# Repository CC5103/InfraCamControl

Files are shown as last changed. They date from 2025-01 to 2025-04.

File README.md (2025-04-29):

# InfraCamControl

**Other Language Versions: [English](README.md) | [中文](README_zh.md) | [日本語](README_jp.md)**

---

## Table of Contents

- [InfraCamControl](#infracamcontrol)
  - [Table of Contents](#table-of-contents)
  - [Overview](#overview)
  - [Features](#features)
  - [Hardware Requirements](#hardware-requirements)
    - [Hardware Diagram](#hardware-diagram)
    - [PiCamera2 Module Filter Adjustment](#picamera2-module-filter-adjustment)
  - [Software Requirements](#software-requirements)
  - [Installation Guide](#installation-guide)
  - [Usage Instructions](#usage-instructions)
  - [System Architecture](#system-architecture)
  - [Face Detection Solutions](#face-detection-solutions)
    - [1. OpenCV Haar Cascade](#1-opencv-haar-cascade)
    - [2. YOLOv8](#2-yolov8)
    - [3. Ultra-Light-Fast](#3-ultra-light-fast)
    - [4. MediaPipe Face Mesh](#4-mediapipe-face-mesh)
  - [Hand Gesture Recognition](#hand-gesture-recognition)
  - [Hardware Connections](#hardware-connections)
  - [Contributing](#contributing)
  - [License](#license)
  - [Troubleshooting](#troubleshooting)
  - [Acknowledgments](#acknowledgments)

---

## Overview

InfraCamControl is a multifunctional smart camera control system based on Raspberry Pi, integrating infrared remote control, computer vision, and gesture recognition technologies. It receives instructions via Slack, supports infrared device control, face and gesture recognition, and automatically adjusts infrared lighting based on ambient light conditions. The system also supports voice interaction with Apple devices, enabling more intelligent device interaction.

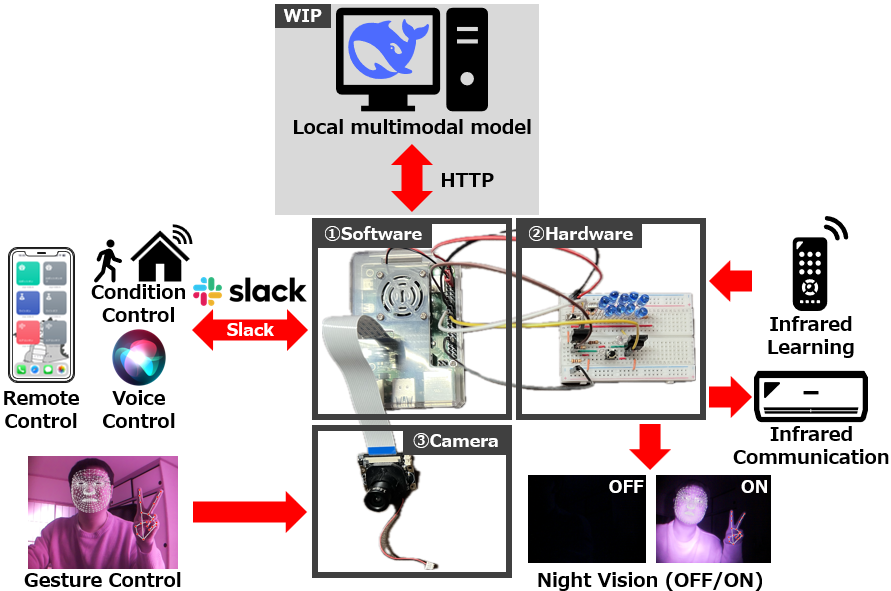
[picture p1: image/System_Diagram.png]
System Diagram


---

## Features

- **Remote Control**: Efficient remote management via Slack.
- **Infrared Learning and Sending**: Supports learning and sending infrared signals.
- **Computer Vision**:
  - Supports multiple face detection methods.
  - Real-time hand gesture recognition.
- **Ambient Light Management**: Automatically adjusts infrared lighting based on light conditions.
- **Multitasking**: Supports multithreading for improved efficiency.
- **Protocol Compatibility**: Supports NEC and Mitsubishi infrared protocols.
- **Apple Device Integration**: Enables smarter control via voice recognition.

---

## Hardware Requirements

- **Raspberry Pi** (Model 4B)
- **PiCamera2** (OV5647 IR-CUT)
- **Infrared LED Emitters** (OSI5LA5A33A-B 940nm) ×9
- **Red LED Indicator Light** (2.3V, 25mA)
- **Diode** (1N5819)
- **Infrared Receiver Module** (OSRB38C9AA)
- **N-channel MOSFETs** (2SK2232) ×2
- **Slide Switch**
- **Button**
- **Resistors**:
  - 2.2Ω (±5%) ×3
  - 10Ω (±5%) ×1
  - 100Ω (±5%) ×1
  - 10kΩ (±5%) ×2

### Hardware Diagram

<div style="display: flex; justify-content: space-between;">
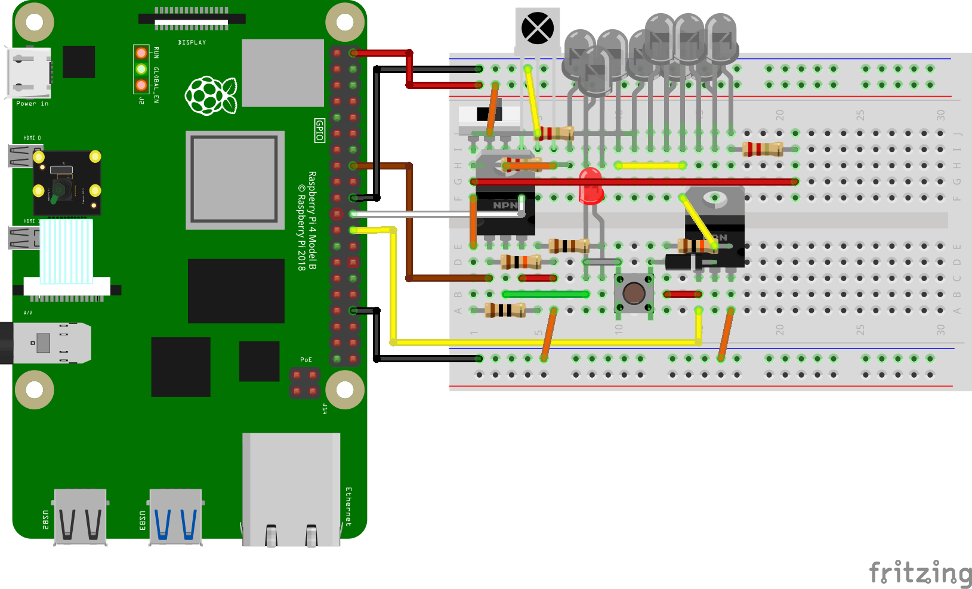
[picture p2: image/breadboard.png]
Breadboard Diagram
  
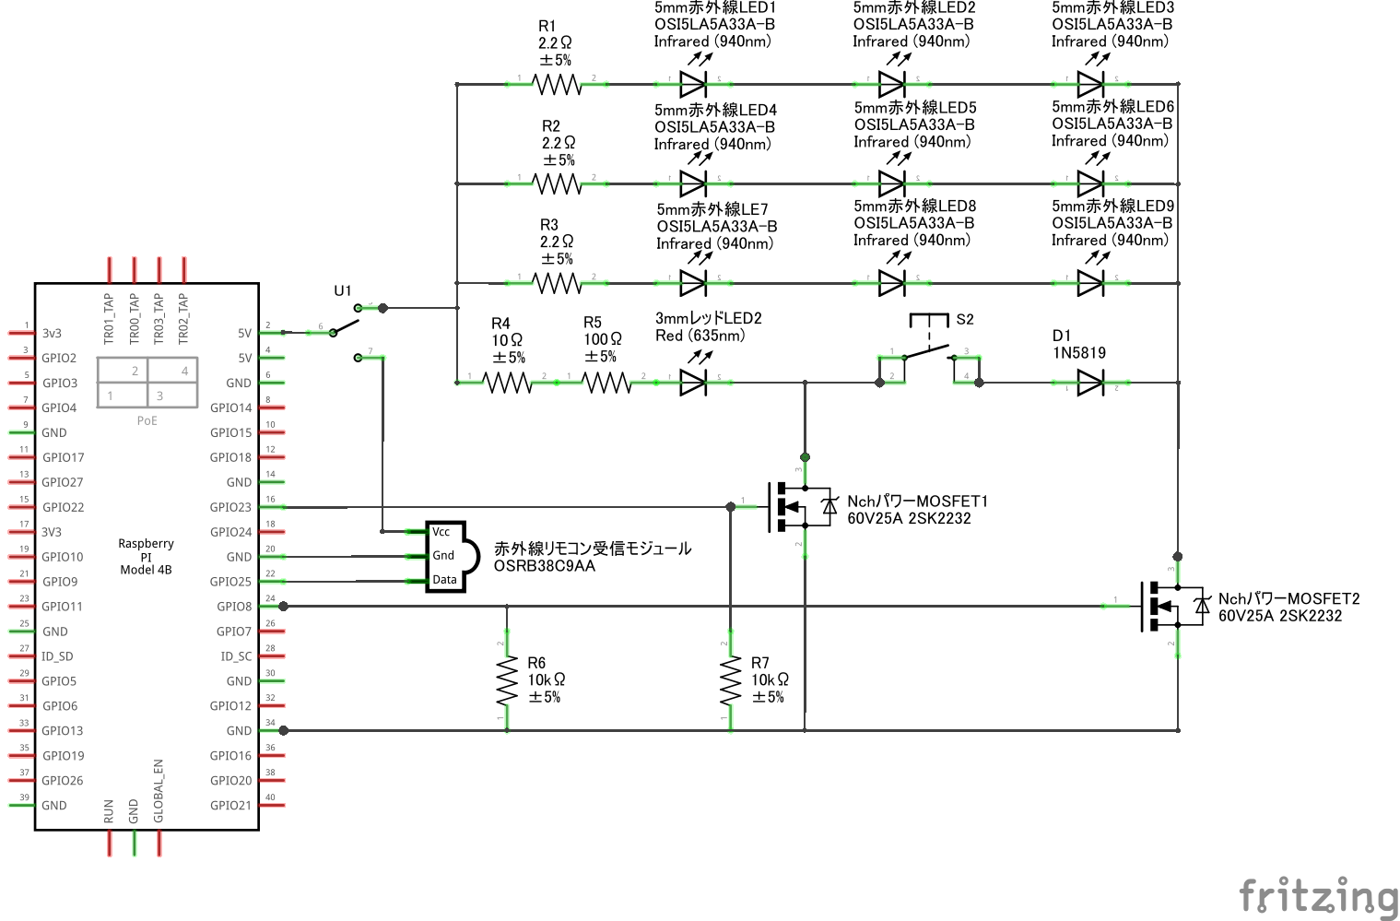
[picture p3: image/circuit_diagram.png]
Circuit Diagram
  
</div>
<br>
<div style="display: flex; justify-content: space-between;">
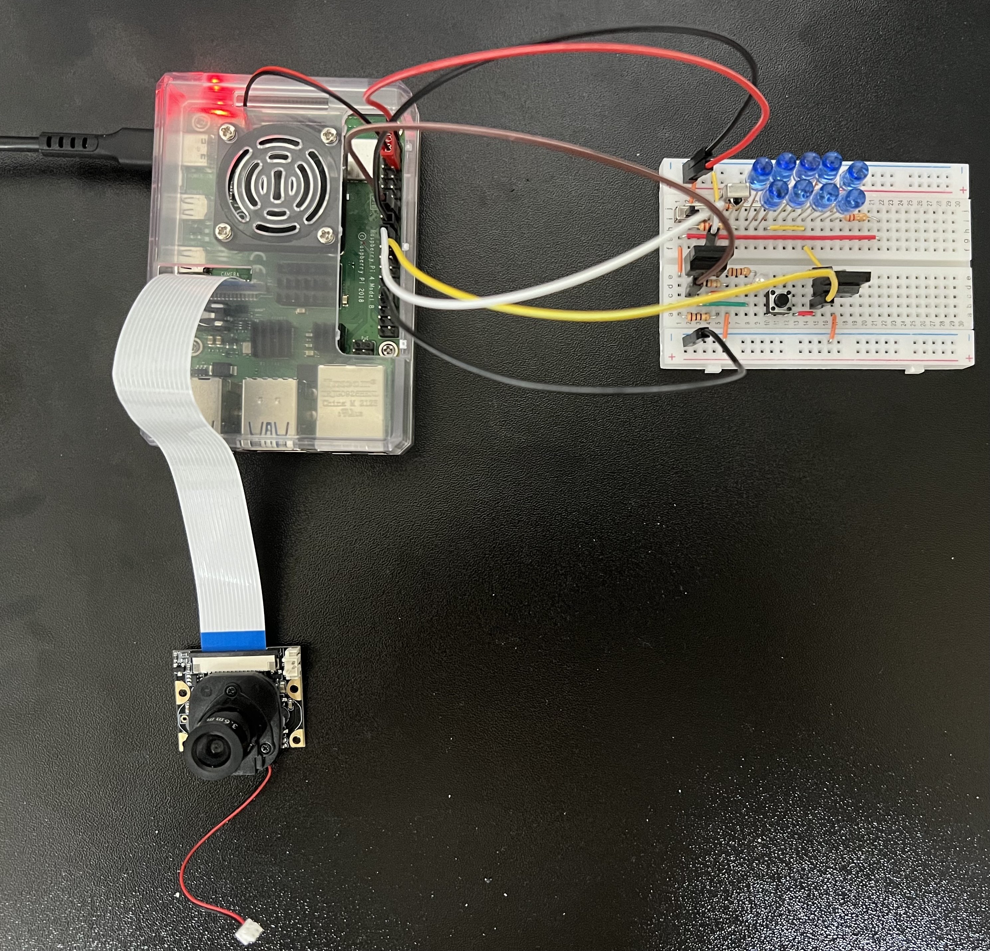
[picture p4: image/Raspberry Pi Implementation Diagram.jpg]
Raspberry Pi Implementation
  
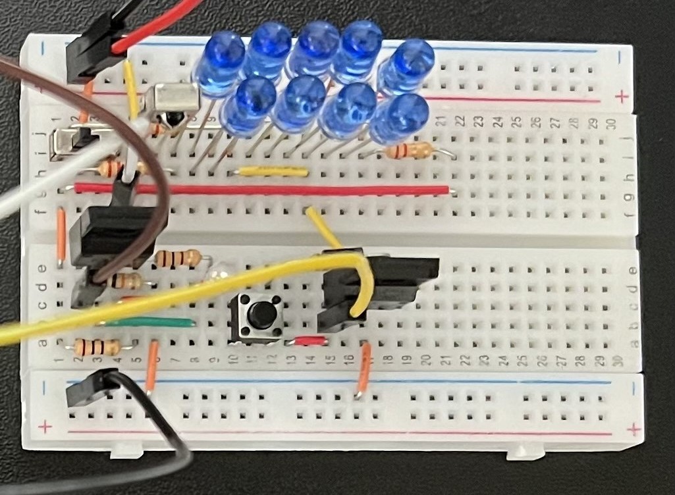
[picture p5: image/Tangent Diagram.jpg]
Tangent Diagram
  
</div>

---

### PiCamera2 Module Filter Adjustment

**Note**: The OV5647 IR-CUT module cannot automatically switch the infrared filter and needs to be manually removed. Follow these steps for non-destructive disassembly:

1. **Remove Screws and Connectors**  
   Unscrew the red-marked screws and unplug the blue-marked connector.  
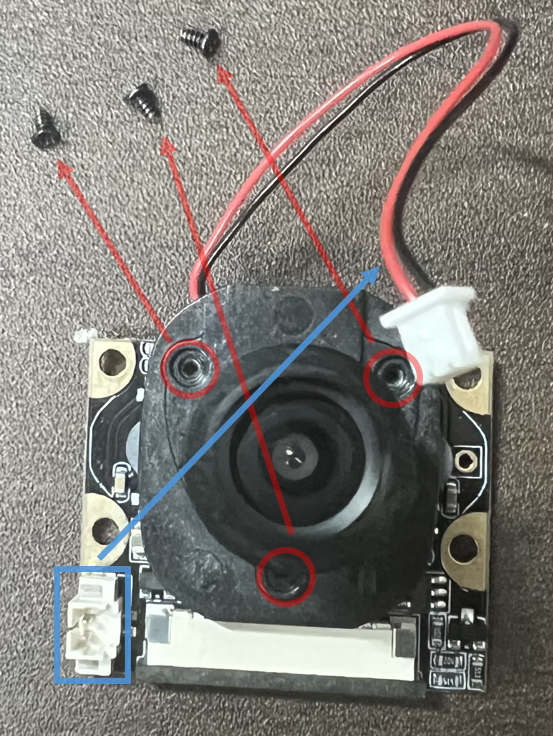
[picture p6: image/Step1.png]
Step 1
   

2. **Adjust Filter and Lever**  
   Move the blue-marked filter to the target position, and gently lift the red-marked lever while keeping it in place. Reattach the screws without reconnecting the connector.
   <div style="display: flex; justify-content: space-between;">
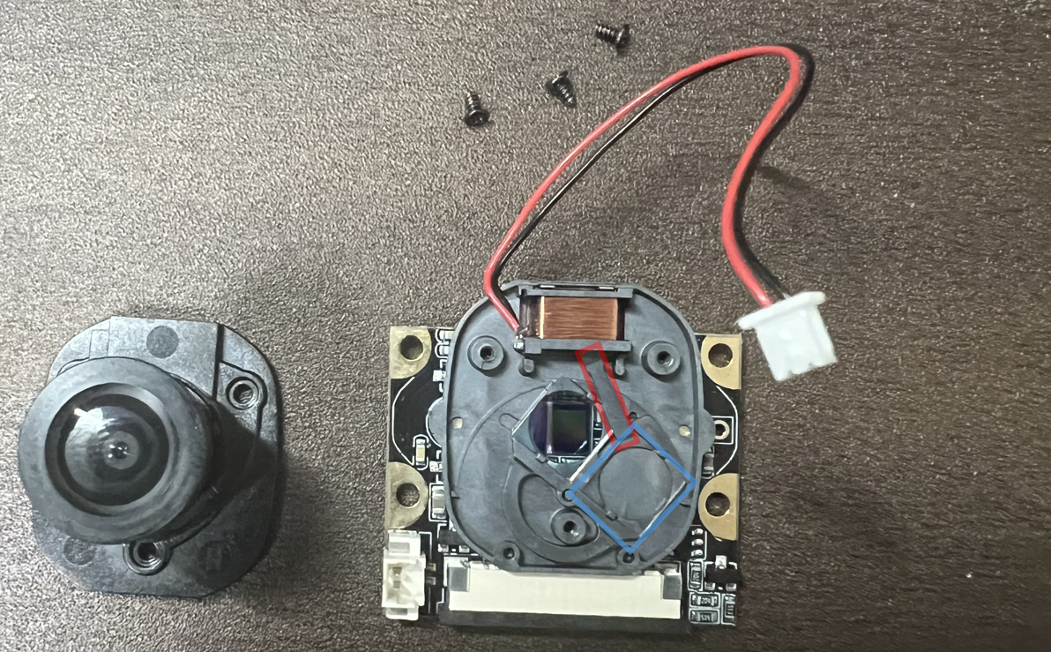
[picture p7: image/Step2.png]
Step 2
   
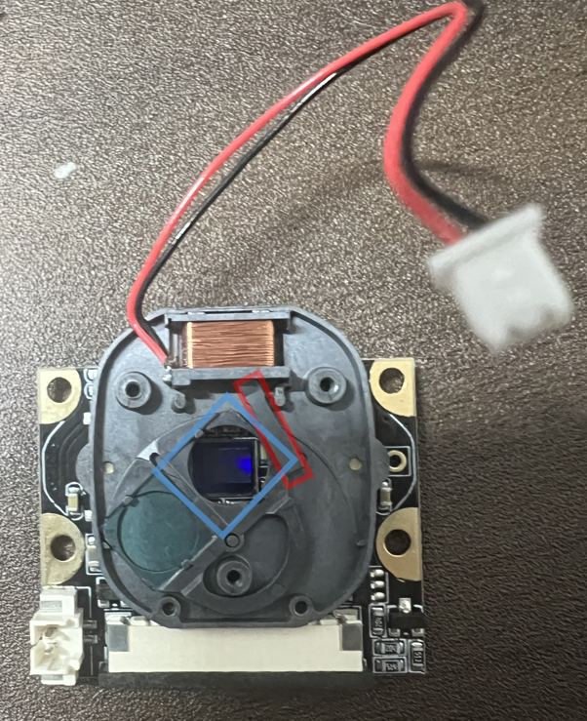
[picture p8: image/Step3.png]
Step 3
   
   </div>

---

## Software Requirements

- **Python 3.x**
- Necessary Python Packages (install via pip):
  - `picamera2`
  - `opencv-python`
  - `pigpio`
  - `slack-sdk`
  - `numpy`
  - `onnxruntime` (for Ultra-Light-Fast model)
  - `ultralytics` (for YOLOv8)
  - `mediapipe`

---

## Installation Guide

1. **Clone the Repository**

   ```bash
   git clone https://github.com/CC5103/InfraCamControl.git
   cd InfraCamControl
   ```

2. **Install Dependencies**

   ```bash
   pip install -r requirements.txt
   ```

3. **Configure Slack Integration**  
   Create a `config.json` file and add your Slack credentials:
   ```json
   {
     "BOT_TOKEN": "your-slack-bot-token",
     "ID": "your-channel-id"
   }
   ```

---

## Usage Instructions

1. **Start the pigpio Daemon**

   ```bash
   sudo pigpiod
   ```

2. **Run the Main Program**

   ```bash
   python3 InfraCamControl/software/main_mediapipe.py
   ```

3. **Create Infrared Signals**  
   Input the following command in Slack to record a signal:

   ```bash
   crate <save_type> <save_key> <save_name>
   ```

   - **Hardware Operation**: Set the switch to the infrared receiver, press the button to record the signal.
   - **Signal Protocol**: Supports NEC or Mitsubishi protocols (940nm).
   - **File Management**: The system automatically generates signal files and updates them in `signal_list.json`.

4. **Send Infrared Signals**

   - **Slack Control**: Type `<save_key>` to trigger the signal (press the button to light up the red indicator for confirmation).
   - **Gesture Control**: Use hand gestures to send the bound signal (spread fingers to activate the system, then the red light automatically turns on as feedback. After activation, perform the corresponding gesture).

---

## System Architecture

The system consists of two main threads:

1. **Slack Message Thread**

   - Listens for commands
   - Manages infrared signal recording and sending

2. **Camera Thread**
   - Face detection
   - Ambient light monitoring and infrared light adjustment

---

## Face Detection Solutions

The system offers the following face detection methods:

### 1. OpenCV Haar Cascade

- **Advantages**: Fast, low resource usage.
- **Disadvantages**: Lower accuracy, sensitive to lighting conditions.
- **Use Case**: Resource-limited environments.

### 2. YOLOv8

- **Advantages**: High detection accuracy, supports multi-target detection.
- **Disadvantages**: Higher resource usage.
- **Use Case**: High-precision applications.

### 3. Ultra-Light-Fast

- **Advantages**: Fast, moderate resource usage.
- **Disadvantages**: Only supports single-face detection.
- **Use Case**: Balanced performance and resource demand.

### 4. MediaPipe Face Mesh

- **Advantages**: High accuracy, supports multi-person detection.
- **Disadvantages**: Requires significant computational resources.
- **Use Case**: Applications needing detailed feature analysis.

---

## Hand Gesture Recognition

The system uses MediaPipe for real-time hand gesture recognition. Supported gestures include:

- **Open Hand**: Activate the system, and the red light turns on.
- **Index Finger**: Turn the light on/off.
- **Index + Middle Finger**: Turn on the air conditioner.
- **Index + Middle + Ring Finger**: Turn off the air conditioner.

---

## Hardware Connections

Key GPIO Interface Descriptions:

- **GPIO8**: Infrared LED Emitters
- **GPIO25**: Infrared Receiver Module
- **GPIO23**: Gesture Recognition Feedback (lights up the red indicator)
- **CSI Interface**: Camera Module Connection
- **Status LED**: Displays system status

---

## Contributing

1. Fork the repository.
2. Create a branch.
   ```bash
   git checkout -b feature/AmazingFeature
   ```
3. Commit your changes.
   ```bash
   git commit -m 'Add some AmazingFeature'
   ```
4. Push the branch.
   ```bash
   git push origin feature/AmazingFeature
   ```
5. Submit a Pull Request.

---

## License

This project is licensed under the GNU General Public License (GPL). See the `LICENSE` file for details.

---

## Troubleshooting

- Ensure the `pigpiod` service is running.
- Check if the Slack configuration is correct.
- Verify hardware connections.
- Confirm the camera module is enabled.

---

## Acknowledgments

- [yhotta240's Infrared Tutorial](https://qiita.com/yhotta240/items/df0f2f92b5dff1d9410b)
- [Casareal BS Blog's Air Conditioner Remote Control Tutorial](https://bsblog.casareal.co.jp/archives/5010)
- [Ultra-Light-Fast-Generic-Face-Detector-1MB](https://github.com/Linzaer/Ultra-Light-Fast-Generic-Face-Detector-1MB)
- [YOLOv8](https://github.com/ultralytics/ultralytics)
- [OpenCV](https://opencv.org/)
- [Google MediaPipe](https://github.com/google/mediapipe)

---

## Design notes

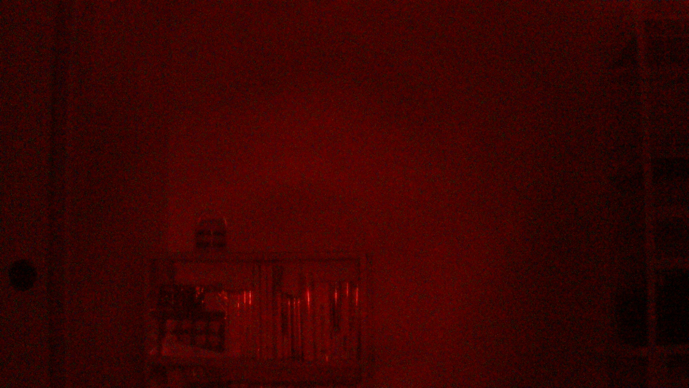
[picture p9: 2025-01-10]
image/Darkness.png

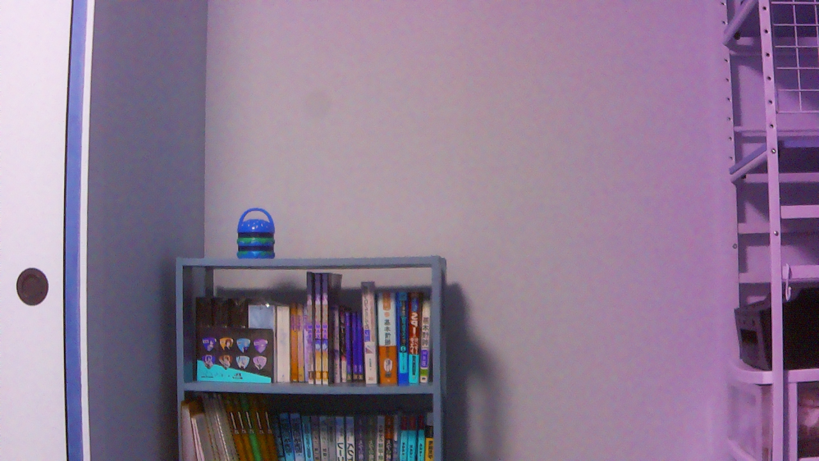
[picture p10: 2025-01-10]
image/Lights_on.png

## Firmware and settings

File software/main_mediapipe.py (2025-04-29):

import cv2
from picamera2 import Picamera2
import threading
import time
import json
from Sender import Sender_class
from signal_processing import save_thread
import cv2
import mediapipe as mp
import detection

def fetch_slack_messages_thread(sender, last_timestamp, json_changed):
    """Fetch slack messages and send signal to IR LED.
    Args:
        sender (Sender_class): Sender class instance.
        last_timestamp (str): Last timestamp of fetched message.
        json_changed (bool): Flag for checking if json file is changed.    
    """
    while True:
        result = sender.fetch_slack_messages_with_retry(last_timestamp)
        if result:
            message, last_timestamp = result
            if message:
                print(f"Received message: {message}")
                if json_changed:
                    try:
                        with open("../IR_signal/signal_list.json") as f: # Load signal map from json file
                            signal_map = json.load(f)
                            json_changed = False
                    except FileNotFoundError:
                        print("Error: signal_list.json not found")
                        exit(1)

                if message in signal_map:
                    sender.send_signal_wave(signal_map[message]) # Send signal to IR LED
                elif message.startswith("crate"):
                    try:
                        if message.split()[1] in ["0", "1"]:
                            save_thread(sender, signal_map, *message.split()[1:]) # Save signal to json file
                            json_changed = True
                        else:
                            sender.client.chat_postMessage(channel=sender.CHANNEL_ID, text=f"Invalid save_type: {message.split()[1]}. \nPlase input 0(NEC) or 1(MITSUBISHI).")
                    except IndexError:
                        sender.client.chat_postMessage(channel=sender.CHANNEL_ID, text=f"Invalid message: {message}. \nPlase input crate <save_type> <save_key> <save_name>.")
                else:
                    sender.client.chat_postMessage(channel=sender.CHANNEL_ID, text=f"Invalid message: {message}. \nPlase input {', '.join(list(signal_map.keys()))} \nor \ncrate <save_type> <save_key> <save_name>.")
                sender.first = True
                last_timestamp = None
        time.sleep(1)

def camera_thread(sender):
    """Capture video from camera and detect face using mediapipe. And hand gesture using mediapipe.
    Args:
        sender (Sender_class): Sender class instance.
    """
    picam2 = Picamera2()
    
    video_config = picam2.create_video_configuration({"size": (640, 480)})
    picam2.configure(video_config)
    
    picam2.set_controls({"AwbEnable": 0})  # Turn off AWB (Because there is no infrared filter the color correction is incorrect which affects the recognition accuracy)
    # picam2.set_controls({"ColourGains": (0.3, 2)})  # Set the color gain to correct the color

    picam2.start()
    
    # Initialize MediaPipe Face Mesh
    mp_face_mesh = mp.solutions.face_mesh
    face_mesh = mp_face_mesh.FaceMesh(static_image_mode=False, max_num_faces=1, min_detection_confidence=0.5, min_tracking_confidence=0.5)
    # Initialize MediaPipe Hands
    mp_hands = mp.solutions.hands
    hands = mp_hands.Hands(static_image_mode=False, min_detection_confidence=0.3, min_tracking_confidence=0.5, max_num_hands=1)

    mp_draw = mp.solutions.drawing_utils
    draw_spec = mp_draw.DrawingSpec(thickness=1, circle_radius=1)
    
    try:
        with open("../IR_signal/signal_list.json") as f: # Load signal map from json file
            signal_map = json.load(f)
    except FileNotFoundError:
        print("Error: config.json not found")
        exit(1)

    # Initialize gesture recognition
    interval = 2 # Interval for gesture recognition. (sec)
    gesture_start_time = time.time() - interval # Initialize gesture start time
    start_bool = False
    
    # Initialize detection class
    detection_ = detection.Detection(sender, mp_face_mesh, face_mesh, mp_hands, hands, mp_draw, draw_spec, signal_map, interval)

    while True:
        frame = picam2.capture_array()
        flipped_frame = cv2.flip(frame, 0)
        frame = cv2.cvtColor(flipped_frame, cv2.COLOR_BGR2RGB)
        frame_copy = frame.copy()

        # Face detection
        detection_.face_detection(frame)
        
        # Hand detection
        gesture_start_time, start_bool, frame = detection_.hand_detection(frame_copy, frame, gesture_start_time, start_bool)

        cv2.imshow("Detection", frame)

        if cv2.waitKey(1) & 0xFF == ord('q'):
            break

        # If the screen is black, turn on the infrared light
        # average_brightness = np.mean(gray)
        # if average_brightness < 20:
        #     sender.pi.write(sender.pin_sender, 1)
        # else:
        #     sender.pi.write(sender.pin_sender, 0)

    picam2.stop()
    cv2.destroyAllWindows()

if __name__ == '__main__':
    sender = Sender_class()
    last_timestamp = None
    json_changed = True

    slack_thread = threading.Thread(target=fetch_slack_messages_thread, args=(sender, last_timestamp, json_changed))
    camera_thread = threading.Thread(target=camera_thread, args=(sender,))

    slack_thread.start()
    camera_thread.start()

    slack_thread.join()
    camera_thread.join()

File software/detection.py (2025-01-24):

import time
import gesture
import threading

class Detection():
    def __init__(self, sender, mp_face_mesh, face_mesh, mp_hands, hands, mp_draw, draw_spec, signal_map, interval):
        """Initialize detection class.
        
        Args:
            sender (Sender_class): Sender class instance.
            mp_face_mesh (mediapipe class): Mediapipe
            face_mesh (mediapipe class): Mediapipe
            mp_hands (mediapipe class): Mediapipe
            hands (mediapipe class): Mediapipe
            mp_draw (mediapipe class): Mediapipe
            draw_spec (mediapipe class): Mediapipe
            signal_map (dict): Signal map.
            interval (int): Interval
        """
        self.sender = sender
        self.mp_face_mesh = mp_face_mesh
        self.face_mesh = face_mesh
        self.mp_hands = mp_hands
        self.hands = hands
        self.mp_draw = mp_draw
        self.draw_spec = draw_spec
        self.signal_map = signal_map
        self.interval = interval

    def face_detection(self, frame):
        """Face detection using mediapipe.

        Args:
            frame (np.array): Image frame.
        """
        face_results = self.face_mesh.process(frame)
        if face_results.multi_face_landmarks:
            for face_landmarks in face_results.multi_face_landmarks:
                self.mp_draw.draw_landmarks(frame, face_landmarks, connections=self.mp_face_mesh.FACEMESH_TESSELATION, landmark_drawing_spec=self.draw_spec, connection_drawing_spec=self.draw_spec)

    def hand_detection(self, frame_copy, frame, gesture_start_time, start_bool):
        """fast hand detection using mediapipe.
        
        Args:
            frame_copy (np.array): Image frame.
            frame (np.array): Image frame. But this is used for drawing.
            gesture_start_time (float): Gesture start time.
            start_bool (bool): Start bool.
        """
        results_precise = self.hands.process(frame_copy)
        if results_precise.multi_hand_landmarks:
            for hand_landmarks in results_precise.multi_hand_landmarks:
                self.mp_draw.draw_landmarks(frame, hand_landmarks, self.mp_hands.HAND_CONNECTIONS)
                # Gesture recognition
                gesture_message = gesture.recognize_gesture(hand_landmarks.landmark)
                # Gesture start
                if gesture_message:
                    if gesture_message == "start":
                        gesture_start_time = time.time()
                        self.sender.pi.write(self.sender.pin_hand, 1)
                        start_bool = True
                    elif time.time() - gesture_start_time < self.interval:
                        gesture_start_time  = gesture_start_time - self.interval
                        # Send signal to IR LED
                        print(f"Received gesture: {gesture_message}")
                        thread = threading.Thread(target=self.sender.send_signal_wave, args=(self.signal_map[gesture_message],))
                        thread.start()

        if time.time() - gesture_start_time > self.interval and start_bool:
            print("Gesture timeout")
            self.sender.pi.write(self.sender.pin_hand, 0)
            start_bool = False

        return gesture_start_time, start_bool, frame
    
if __name__ == '__main__':
    pass

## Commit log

2025-01-06 Add CSV files for AC control and light signal configurations
    [ac_start.csv, ac_stop.csv, light.csv]
2025-01-06 Add CAD drawing file CAD_drawing.fzz
    [CAD_drawing.fzz]
2025-01-07 Fix message unpacking in fetch_slack_messages_thread for improved error handling
    [main.py]
2025-01-07 Fix signal type descriptions in signal_read function
    [signal_processing.py]
2025-01-07 Fix message logging in fetch_slack_messages_thread to ensure messages are printed when received
    [main.py]
2025-01-08 Increase sleep duration in fetch_slack_messages_thread to improve message processing stability
    [main.py]
2025-01-10 Update the README file to include the method for removing the infrared filter.
2025-01-22 Add face detection functionality using ONNX model and integrate with camera capture
2025-01-22 Configure video settings for camera thread to use a resolution of 640x480
2025-01-23 Remove unused imports and update camera thread documentation for clarity
2025-01-23 Add gesture recognition functionality and integrate with camera thread
2025-01-23 Add main_mediapipe.py for camera video capture and gesture recognition integration
2025-01-24 Added a prompt for lighting up the LED after gesture recognition.
2025-01-24 Add error handling for message parsing in Slack command processing
    [main.py, main_mediapipe.py, main_ultralight.py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]
2025-01-24 Fix type comparison for message parsing in crate command
    [main.py, main_mediapipe.py, main_ultralight.py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]
2025-01-24 Fix typo in hand detection method and implement threading for signal sending
    [detection.py, main_mediapipe.py]
2025-01-24 File organization and categorization with folders
    [CAD_drawing.fzz, ac_start.csv, ac_stop.csv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]
2025-01-28 Update pin assignments in Sender class constructor for improved functionality
2025-01-28 Updating hardware and red LED feedback for recognition.
2025-01-28 Update the resistor list in the README and change the quantity of 10kΩ resistors from 1 to 2.
2025-01-28 Add a 10Ω resistor to the README.
2025-01-28 Add gesture recognition functionality to detect raised fingers and reduce misrecognition rates.
2025-01-29 Update Fritzing CAD (.fzz) files: enhance gesture recognition and upgrade to higher brightness LED components
    [CAD_drawing.fzz]
2025-01-29 Fix circuit connection errors
    [CAD_drawing.fzz]
2025-01-31 Refined and optimized the circuit layout for better organization.
    [CAD_drawing.fzz]
2025-02-08 Redesigned circuit: 3 to 9 infrared LEDs, added diodes.
    [CAD_drawing.fzz]
2025-02-08 Added the actual wiring diagram after circuit modification.
2025-02-08 README: Update resistor list to include 2.2Ω and remove 47Ω
2025-02-14 Disable AWB in the camera thread
2025-02-14 README: Update GPIO pin assignments for infrared receiver and gesture feedback
